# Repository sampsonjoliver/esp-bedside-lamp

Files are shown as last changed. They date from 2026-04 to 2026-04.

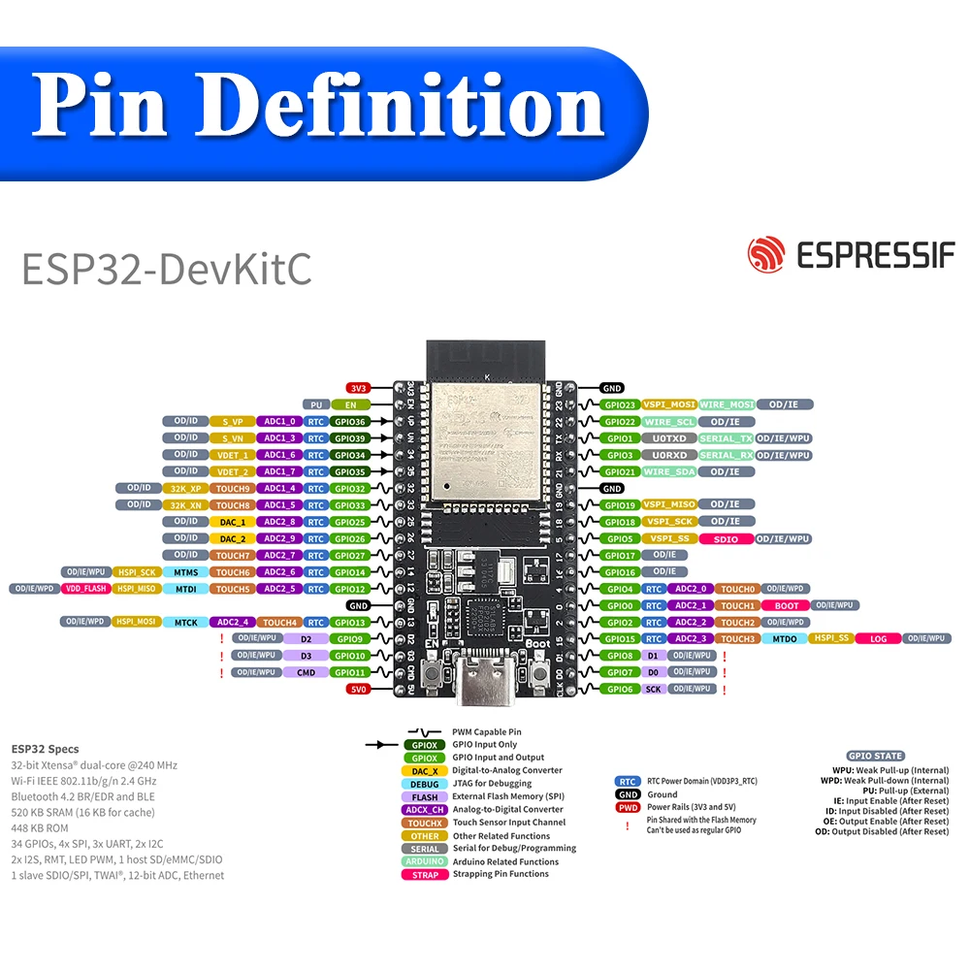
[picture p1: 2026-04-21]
firmware/esp32-devkitc/esp32d-typec-pin-diagram.webp

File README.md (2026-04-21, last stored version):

# esp-bedside-lamp

## Getting Started

Install esphome:

```bash
python3 -m venv venv
source venv/bin/activate
pip install esphome
```

Deploy and run changes:
`esphome run lamp.yaml`

## Useful Commands

- View Logs: `esphome logs my_device.yaml` (Great for debugging code snippets).
- Validate YAML: `esphome config my_device.yaml` (Checks for syntax errors without compiling).
- Clean Build: `esphome clean my_device.yaml` (If things get "janky" with the cache).
- Set up additional device: `esphome wizard my_device.yaml`

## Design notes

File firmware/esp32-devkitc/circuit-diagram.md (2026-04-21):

# Circuit Diagram

```mermaid
flowchart TD
    USBC["USB-C PD Decoy\n(5V input)"]

    subgraph POWER ["5V Rail"]
        CAP1["100µF electrolytic\n(bulk smoothing)"]
    end

    subgraph ESP ["ESP32-DevKitC V4"]
        VIN["VIN"]
        CAP2["100nF ceramic\n(decoupling)"]
        GPIO16["GPIO16"]
        GPIO4["GPIO4"]
        GPIO17["GPIO17 (CLK)"]
        GPIO18["GPIO18 (DT)"]
        GPIO19["GPIO19 (BTN)"]
        GND_ESP["GND"]
    end

    subgraph STRIP ["SK6812 WWA Strip (1m)"]
        VCC1["VCC (start)"]
        DAT["Data"]
        GND1["GND (start)"]
        VCC2["VCC (end)"]
        GND2["GND (end)"]
    end

    RES["1MΩ resistor"]
    TOUCH["Copper Touch Plate"]

    subgraph ENC ["Rotary Encoder (EC11)"]
        CLK["CLK"]
        DT["DT"]
        BTN["BTN"]
        GND_ENC["GND"]
    end

    GND_COMMON["Common GND"]

    USBC --> POWER
    POWER --> VIN
    POWER --> VCC1
    POWER --> VCC2
    CAP1 --- GND_COMMON

    VIN --- CAP2
    CAP2 --- GND_ESP

    GPIO16 --> DAT
    GPIO4 --> RES --> TOUCH

    GPIO17 --- CLK
    GPIO18 --- DT
    GPIO19 --- BTN

    GND_ESP --- GND_COMMON
    GND1 --- GND_COMMON
    GND2 --- GND_COMMON
    GND_ENC --- GND_COMMON
```

## Wiring Summary

### Power

| From | To | Wire |
|---|----|---|
| USB-C PD decoy 5V | ESP32 VIN | Red |
| USB-C PD decoy 5V | SK6812 VCC (start) | Red |
| USB-C PD decoy 5V | SK6812 VCC (end) | Red |
| USB-C PD decoy GND | Common GND | White |
| Common GND | ESP32 GND | White |
| Common GND | SK6812 GND (start) | White |
| Common GND | SK6812 GND (end) | White |
| Common GND | Encoder GND | White |

### Signals

| From | To | Via | Notes |
|---|----|-----|---|
| ESP32 GPIO16 | SK6812 Data | Green | RMT data line |
| ESP32 GPIO4 | Copper touch plate | 1MΩ resistor | Static protection |
| Encoder CLK | ESP32 GPIO17 | — | Internal pull-up enabled |
| Encoder DT | ESP32 GPIO18 | — | Internal pull-up enabled |
| Encoder BTN | ESP32 GPIO19 | — | Internal pull-up enabled |

### Decoupling Capacitors

| Capacitor | Placement | Purpose |
|---|---|---|
| 100µF electrolytic | 5V/GND near LED strip VCC | Absorbs current spikes when LEDs switch |
| 100nF ceramic | ESP32 VIN/GND | Suppresses high-frequency noise |

## Notes

- 100µF electrolytic cap: across 5V/GND near LED strip input — absorbs current spikes when LEDs switch
- 100nF ceramic cap: across ESP32 VIN/GND — suppresses high-frequency noise
- 1MΩ resistor: in series between GPIO4 and touch plate — protects pin from static discharge
- Encoder CLK/DT/BTN use ESP32 internal pull-ups (configured in ESPHome)
- SK6812 powered at both ends to avoid voltage drop across 1m strip

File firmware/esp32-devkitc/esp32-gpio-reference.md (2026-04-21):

# ESP32 DevKitC GPIO Reference

Source: `esp32d-typec-pin-diagram.webp` (Espressif official pin definition diagram)

## Board Specs

| | |
|-|-|
| CPU | 32-bit Xtensa dual-core @ 240 MHz |
| Wi-Fi | 802.11 b/g/n 2.4 GHz |
| Bluetooth | 4.2 BR/EDR and BLE |
| SRAM | 520 KB (16 KB cache) |
| ROM | 448 KB |
| GPIOs | 34 total |
| ADC | 12-bit, 2 × SAR (ADC1 + ADC2) |
| Interfaces | 4× SPI, 3× UART, 2× I2C, 2× I2S, 1× host SD/eMMC/SDIO |
| PWM | LED PWM controller |
| Other | RMT, touch sensor, Ethernet MAC |

---

## Pin Table

| Pin | GPIO State¹ | Alternate Functions | Notes |
|-----|---|---|---|
| **3V3** | PWR | — | 3.3 V output |
| **5V** | PWR | — | 5 V output (from USB) |
| **GND** | GND | — | Ground |
| **EN** | — | — | Chip enable (active high) |
| **GPIO0** | OD/IE/WPU | RTC, ADC2_1, TOUCH1, BOOT | Strapping pin — LOW at boot = flash mode |
| **GPIO1** | OD/IE/WPU | U0TXD, SERIAL_TX | UART0 TX — used for flashing/logging |
| **GPIO2** | OD/IE/WPD | RTC, ADC2_2, TOUCH2 | Strapping pin; must be HIGH or floating at boot |
| **GPIO3** | OD/IE/WPU | U0RXD, SERIAL_RX | UART0 RX — used for flashing/logging |
| **GPIO4** | OD/IE/WPD | RTC, ADC2_0, TOUCH0 | Safe general-purpose GPIO |
| **GPIO5** | OD/IE/WPU | VSPI_SS, SDIO | SPI chip select |
| **GPIO6** | OD/IE/WPU | SCK | ⚠️ Shared with internal flash — do not use |
| **GPIO7** | OD/IE/WPU | D0 | ⚠️ Shared with internal flash — do not use |
| **GPIO8** | OD/IE/WPU | D1 | ⚠️ Shared with internal flash — do not use |
| **GPIO9** | OD/IE/WPU | D2 | ⚠️ Shared with internal flash — do not use |
| **GPIO10** | OD/IE/WPU | D3 | ⚠️ Shared with internal flash — do not use |
| **GPIO11** | OD/IE/WPU | CMD | ⚠️ Shared with internal flash — do not use |
| **GPIO12** | OD/IE/WPD | MTDI, HSPI_MISO, TOUCH5, ADC2_5, RTC, VDD_FLASH | Strapping pin — affects flash voltage; avoid |
| **GPIO13** | OD/IE/WPD | MTCK, HSPI_MOSI, TOUCH4, ADC2_4, RTC | Safe general-purpose GPIO |
| **GPIO14** | OD/IE/WPU | MTMS, TOUCH6, ADC2_6, RTC | Safe general-purpose GPIO |
| **GPIO15** | OD/IE/WPU | MTDO, HSPI_SS, TOUCH3, ADC2_3, RTC, LOG | Strapping pin; outputs log messages at boot |
| **GPIO16** | OD/IE | — | Clean GPIO, RMT-capable — good for addressable LEDs |
| **GPIO17** | OD/IE | — | Clean GPIO — good for encoder CLK |
| **GPIO18** | OD/IE | VSPI_SCK | SPI clock; usable as GPIO |
| **GPIO19** | OD/IE | VSPI_MISO | SPI MISO; usable as GPIO |
| **GPIO21** | OD/IE | WIRE_SDA | I2C SDA |
| **GPIO22** | OD/IE | WIRE_SCL | I2C SCL |
| **GPIO23** | OD/IE | VSPI_MOSI, WIRE_MOSI | SPI MOSI; usable as GPIO |
| **GPIO25** | OD/ID | DAC_1, ADC2_8, RTC | DAC output channel 1 |
| **GPIO26** | OD/ID | DAC_2, ADC2_9, RTC | DAC output channel 2 |
| **GPIO27** | OD/ID | TOUCH7, ADC2_7, RTC | Touch-capable GPIO |
| **GPIO32** | OD/ID | TOUCH9, ADC1_4, RTC, 32K_XP | Touch-capable; ADC1 (works alongside Wi-Fi) |
| **GPIO33** | OD/ID | TOUCH8, ADC1_5, RTC, 32K_XN | Touch-capable; ADC1 (works alongside Wi-Fi) |
| **GPIO34** | Input only | ADC1_6, RTC | Input only — no internal pull-up/pull-down |
| **GPIO35** | Input only | VDET_2, ADC1_7, RTC | Input only — no internal pull-up/pull-down |
| **GPIO36** | Input only | ADC1_0, RTC, S_VP | Input only — no internal pull-up/pull-down |
| **GPIO39** | Input only | ADC1_3, RTC, S_VN | Input only — no internal pull-up/pull-down |

---

## GPIO State Legend

| Code | Meaning |
|---|---|
| WPU | Weak Pull-up (Internal) |
| WPD | Weak Pull-down (Internal) |
| PU | Pull-up (External) |
| IE | Input Enable (After Reset) |
| ID | Input Disabled (After Reset) |
| OE | Output Enable (After Reset) |
| OD | Output Disabled (After Reset) |

---

## Quick Reference: Pins to Avoid

| Pin(s) | Reason |
|---|---|
| GPIO6–11 | Shared with internal SPI flash — will crash the chip |
| GPIO0 | Strapping pin: LOW at boot triggers flash mode |
| GPIO2 | Strapping pin; must be HIGH or floating at boot |
| GPIO12 | Strapping pin: HIGH at boot changes flash voltage (3.3 V → 1.8 V) |
| GPIO15 | Strapping pin: LOW silences boot log output |
| GPIO1, GPIO3 | UART0 TX/RX — needed for serial flashing and ESPHome logging |
| GPIO34–39 | Input-only — cannot drive output |

---

## Quick Reference: Good Pins for This Project

| Use | Recommended Pin | Why |
|-----|---|-----|
| SK6812 data (RMT) | GPIO16 | Clean, RMT-capable, no conflicts |
| Rotary encoder CLK | GPIO17 | Clean GPIO |
| Rotary encoder DT | GPIO18 | Clean GPIO |
| Rotary encoder button | GPIO19 | Clean GPIO |
| Copper touch plate | GPIO4 | TOUCH0, already in prototype |

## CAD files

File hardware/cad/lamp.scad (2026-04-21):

// =============================================
// Lamp Model
// =============================================

// --- Overall dimensions ---
lamp_width   = 230;  // total length along long axis (mm)
lamp_depth   = 120;  // total depth along short axis (mm)
total_height = 160;  // assembled height base + diffuser (mm)

// --- Base ---
base_height           = 40;   // total base height (mm)
base_floor_thickness  = 15;   // base floor thickness — must clear ESP32 pocket + clip groove (mm)
base_wall_thickness   = 5;    // base side wall thickness (mm) — must exceed diffuser_wall_thickness; difference is tenon width
base_diffuser_overlap               = 10;   // how far the diffuser clamps down over the base top (mm)

// --- Diffuser ---
diffuser_wall_thickness     = 3;  // side wall thickness (mm)
diffuser_top_thickness      = 3;  // top wall thickness — thicker to give 1.5mm under disc pocket (mm)
diffuser_top_roundover      = 2;  // roundover radius on top outer edge (mm)

// --- Copper disc (top button) ---
disc_r             = 40;   // disc radius (mm)
disc_thickness     = 2;    // disc thickness (mm)
disc_pocket_depth  = 1.5;  // pocket depth — disc proud by (disc_thickness - disc_pocket_depth) = 0.5mm

// --- LED form ---
led_gap             = 32;  // inset from outer lamp wall to LED form outer surface (mm)
led_height          = 100; // LED form height (mm)
led_wall_thickness  = 2;   // LED form wall thickness (mm)
led_clip_depth      = 2;   // depth of locating rim that seats into base floor groove (mm)
led_hole_r          = 6;   // radius of cable pass-through holes in LED form walls (mm)

// --- Wire routing ---
wire_r = 2;  // radius of vertical wire channel through diffuser top and LED form (mm)

// --- EC11 rotary encoder (front face) ---
enc_shaft_r     = 3.25; // shaft hole radius — 6.5mm diameter for EC11 (mm)
enc_body_width  = 14;   // encoder body cavity width (mm)
enc_body_depth  = 15;   // encoder body cavity depth into base wall (mm)
enc_body_height = 14;   // encoder body cavity height (mm)

// --- USB-C decoy board (rear face) ---
usbc_port_width   = 9.5;  // USB-C port opening width (mm)
usbc_port_height  = 3.5;  // USB-C port opening height (mm)
usbc_board_width  = 10.7; // board width (mm)
usbc_board_length = 28;   // board length — extends inward from rear wall (mm)
usbc_board_height = 7;    // board + component height — measure and update (mm)

// --- ESP32 board (lies flat on base floor, inside LED form) ---
// Active: ESP32-S3 Pico — swap values below to use WROOM-32D for prototyping
// ESP32-WROOM-32D DevKit: esp_length=52, esp_width=28, esp_component_height=10
esp_length           = 51;   // board length (mm) — verify against datasheet
esp_width            = 21;   // board width  (mm) — verify against datasheet
esp_component_height = 4;    // tallest component height (mm) — verify against datasheet
esp_pocket_depth     = 1.5;  // locating pocket depth in base floor (mm)

// --- Render quality ---
$fn = 64;

// --- Derived (do not edit) ---
diff_h  = total_height - base_height + base_diffuser_overlap;  // diffuser height including base_diffuser_overlap
pill_r  = lamp_depth / 2;                        // end-cap radius of pill shape
pill_cx = (lamp_width - lamp_depth) / 2;         // centre-to-centre half-spacing of pill cylinders
led_r   = pill_r - led_gap;                      // LED form outer radius
enc_z   = (base_height - base_diffuser_overlap) / 2;           // z-centre of encoder shaft and USB-C port


// =============================================
// Helper: pill-shaped hull of two cylinders
// =============================================
module pill(r, h) {
    hull() {
        translate([-pill_cx, 0, 0]) cylinder(r=r, h=h);
        translate([ pill_cx, 0, 0]) cylinder(r=r, h=h);
    }
}


// =============================================
// Diffuser outer shell with top edge roundover.
// Uses minkowski + sphere for true roundover on all
// top edges, then clips the bottom flat.
// =============================================
module diffuser_outer() {
    r = diffuser_top_roundover;
    intersection() {
        minkowski() {
            pill(pill_r - r, diff_h - r);
            sphere(r=r);
        }
        // Clip bottom flat — minkowski expands downward by r
        translate([0, 0, diff_h / 2])
            cube([lamp_width * 2, lamp_depth * 2, diff_h], center=true);
    }
}

// =============================================
// Diffuser
// Hollow pill, open bottom, 3mm side walls, 3mm top.
// Top outer edge has a 2mm roundover.
// Top has a pocket for the copper disc and a
// vertical wire channel routing to the ESP32.
// Print orientation: upright on open bottom.
// =============================================
module diffuser() {
    color("white", 0.85)
    difference() {
        diffuser_outer();

        // Inner cavity — open at bottom, diffuser_top_thickness top wall
        translate([0, 0, -0.1])
            pill(pill_r - diffuser_wall_thickness, diff_h - diffuser_top_thickness + 0.1);

        // Copper disc pocket — disc protrudes 0.5mm proud of top surface
        translate([0, 0, diff_h - disc_pocket_depth])
            cylinder(r=disc_r, h=disc_pocket_depth + 0.1);

        // Vertical wire channel — runs full height, exits through pocket floor
        translate([0, 0, -0.1])
            cylinder(r=wire_r, h=diff_h + 0.2);
    }
}


// =============================================
// Base
// Hollow pill, 3mm side walls, 15mm floor, open top.
// Top base_diffuser_overlap region is stepped to form friction-fit
// tenon for the diffuser.
// Front face (-Y): EC11 encoder shaft hole + body cavity.
// Rear face  (+Y): USB-C port hole + board pocket.
// Floor: ESP32 locating pocket + LED form clip groove.
// Print orientation: upright on floor.
// =============================================
module base() {
    color("#5C3A1E")
    difference() {
        pill(pill_r, base_height);

        // Inner cavity — base_floor_thickness floor, open top
        translate([0, 0, base_floor_thickness])
            pill(pill_r - base_wall_thickness, base_height - base_floor_thickness + 0.1);

        // Friction-fit tenon — steps top base_diffuser_overlap region inward by diffuser_wall_thickness
        // so diffuser inner wall seats flush over the top of the base
        translate([0, 0, base_height - base_diffuser_overlap])
            difference() {
                pill(pill_r + 0.1, base_diffuser_overlap + 0.1);
                pill(pill_r - diffuser_wall_thickness, base_diffuser_overlap + 0.2);
            }

        // EC11 encoder shaft hole — front face (-Y), centred horizontally and vertically
        translate([0, -(pill_r + 0.1), enc_z])
            rotate([-90, 0, 0])
                cylinder(r=enc_shaft_r, h=base_wall_thickness + 5);

        // EC11 encoder body cavity — pocket behind front wall, aligned with shaft
        translate([-enc_body_width/2, -(pill_r - base_wall_thickness), enc_z - enc_body_height/2])
            cube([enc_body_width, enc_body_depth, enc_body_height]);

        // LED form clip groove — ring channel in base floor that the LED form rim seats into
        translate([0, 0, base_floor_thickness - led_clip_depth])
            difference() {
                pill(led_r + 0.1, led_clip_depth + 0.1);
                pill(led_r - led_wall_thickness, led_clip_depth + 0.1);
            }

        // ESP32 locating pocket — centred in base floor, board lies flat
        translate([-esp_length/2, -esp_width/2, base_floor_thickness - esp_pocket_depth])
            cube([esp_length, esp_width, esp_pocket_depth + 0.1]);

        // USB-C port opening — rear face (+Y), aligned vertically with encoder
        translate([-usbc_port_width/2, pill_r - base_wall_thickness - 0.1, enc_z - usbc_port_height/2])
            cube([usbc_port_width, base_wall_thickness + 0.2, usbc_port_height]);

        // USB-C decoy board pocket — friction fit, board drops in from open top
        // connector end at rear wall, board extends inward
        translate([-usbc_board_width/2, pill_r - base_wall_thickness - usbc_board_length, enc_z - usbc_board_height/2])
            cube([usbc_board_width, usbc_board_length, usbc_board_height]);
    }
}


// =============================================
// LED Form
// Hollow pill tube — LED strip winds around outside.
// Bottom rim seats into clip groove in base floor.
// Front and rear walls have cable pass-through holes
// for routing encoder and USB-C wires to the ESP32.
// Print orientation: upright.
// =============================================
module led_form() {
    color("white", 0.4)
    difference() {
        // Outer shell — rim extends led_clip_depth below z=0 to seat in groove
        translate([0, 0, -led_clip_depth])
            pill(led_r, led_height + led_clip_depth);
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

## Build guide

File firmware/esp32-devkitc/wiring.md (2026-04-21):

# Wiring Plan

## Connector Standard

All internal connections use **JST-SM** (the connector type pre-fitted on the SK6812 WWA strip).

Buy JST-SM pre-crimped pigtail assortment (2, 3, 4-pin) — search AliExpress "JST SM pigtail pre-crimped".

**Wire gauge:** 22 AWG for 5V power runs, 26 AWG for all signal wires.

## Component Terminations

| Component | Existing termination | Conversion |
|---|---|---|
| PD decoy | Rising cage clamps | Screw 22 AWG wire directly into clamps — cage clamp is the termination. No JST needed here. |
| ESP32 | Through-holes (solder direct, not header pins) | Solder 26 AWG wires to the relevant through-holes. Terminate each group with JST-SM female on the other end. |
| SK6812 WWA strip | JST-SM male (pre-fitted) | Buy matching JST-SM 3-pin female pigtail — plug straight in, no modification needed. |
| Rotary encoder | Bare metal prongs | Solder 26 AWG wires to each prong (CLK, DT, BTN, GND). Terminate with JST-SM 4-pin female. |
| Copper touch plate | Bare copper disk | Solder single 26 AWG wire to disk. Run 1MΩ resistor inline. Terminate with JST-SM 2-pin female (signal + GND). |

## ESP32 Through-Holes to Solder

| Through-hole | Function | Wire to |
|---|---|---|
| VIN | 5V power in | PD decoy 5V |
| GND | Ground | Common GND |
| GPIO4 | Touch plate signal | 1MΩ → touch plate |
| GPIO16 | SK6812 data | Strip data pin |
| GPIO17 | Encoder CLK | Encoder CLK prong |
| GPIO18 | Encoder DT | Encoder DT prong |
| GPIO19 | Encoder button | Encoder BTN prong |

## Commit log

2026-04-21 Add lamp CAD file
    [lamp.scad]
2026-04-21 Initialise esphome device
2026-04-21 Add esp32 reference files
2026-04-21 Overhaul project structure
    [lamp.scad]
2026-04-21 Define circuit diagram
2026-04-21 Add wiriing plan
